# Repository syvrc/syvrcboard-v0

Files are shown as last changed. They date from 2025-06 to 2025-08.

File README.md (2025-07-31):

## syvrcboard v0
> `syvrcboard v0` was and is my very first attempt on making a custom mechanical keyboard from scratch although before making this i had made a [macropad](https://github.com/syvrc/syvrcpad) before  

| light bg                               |
| -------------------------------------- |
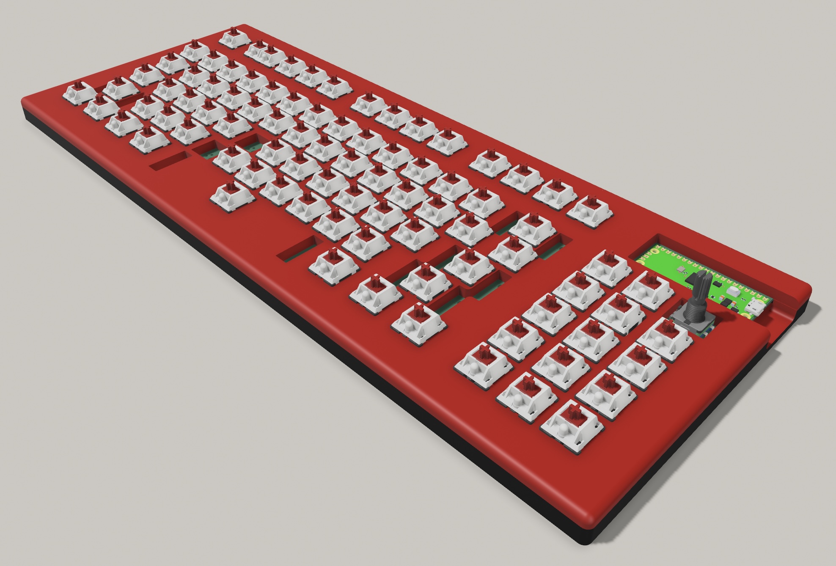
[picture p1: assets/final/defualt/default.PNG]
|  |

| dark bg                                                |
| ------------------------------------------------------ |
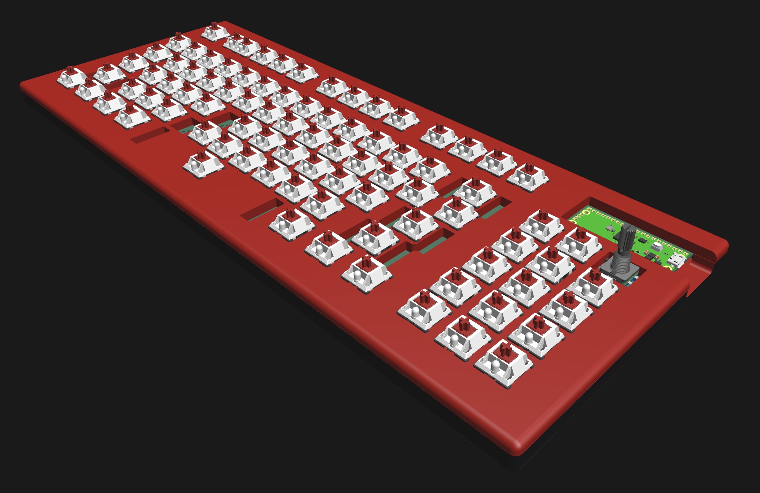
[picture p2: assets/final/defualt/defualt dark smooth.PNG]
|  |

> `syvrcboard v0` is a custom TKL Mechanical Keyboard with `10 Macro Keys`, a `Rotary Encoder Switch` and is powered by `Raspberry Pi Pico` board, the keyboard's silkscreen art is solely `demon slayer` based  

Features:
- 88x keys
- a rotary encoder switch for volume , brightness etc
- [custom TKL layout w/ 11 macrokeys](#layout)
- demon slayer themed pcb silkscreen art!!
- works with Raspberry Pi Pico
- KMK firmware (subject to change)
- sandwich mount

## schematic
| dev board (rpi pico)                | switch matrix
:------------------------------------:|:---------------------------------:
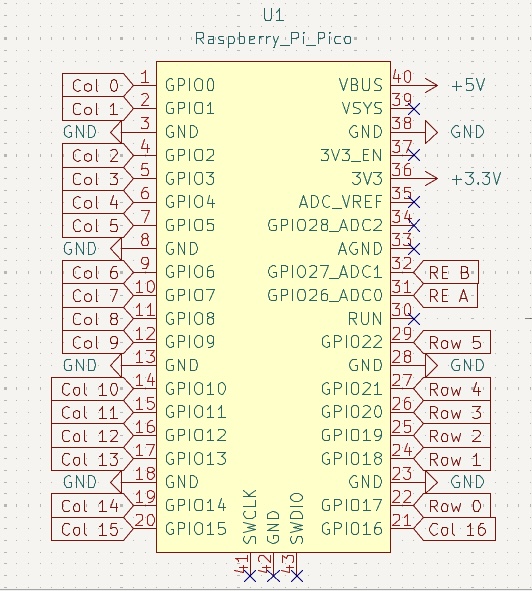
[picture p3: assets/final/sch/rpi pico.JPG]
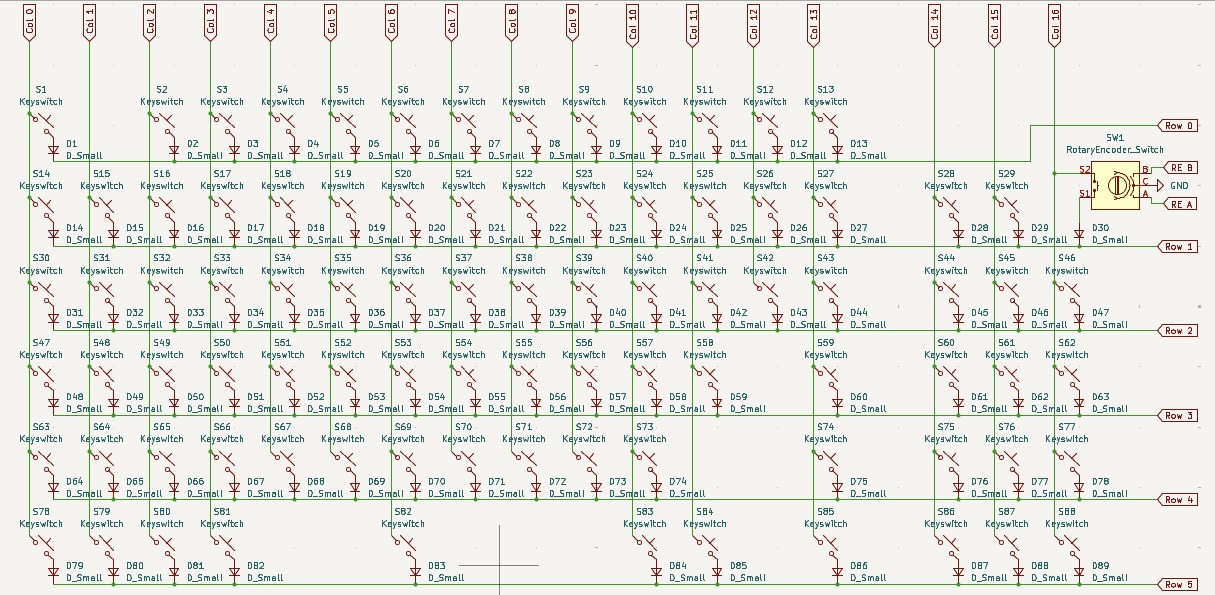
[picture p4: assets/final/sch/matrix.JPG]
 | 

## pcb
| front                            |
| -------------------------------- |
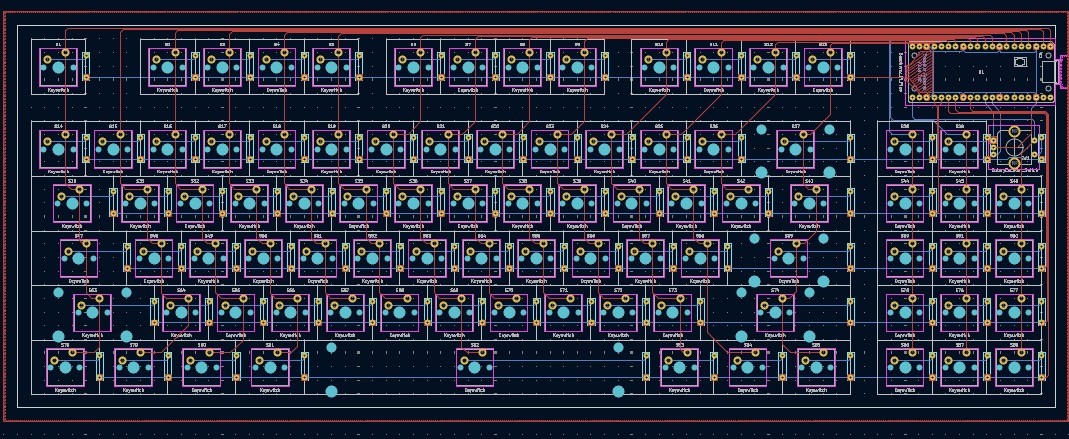
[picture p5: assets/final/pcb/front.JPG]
|  |

| back                            |
| ------------------------------- |
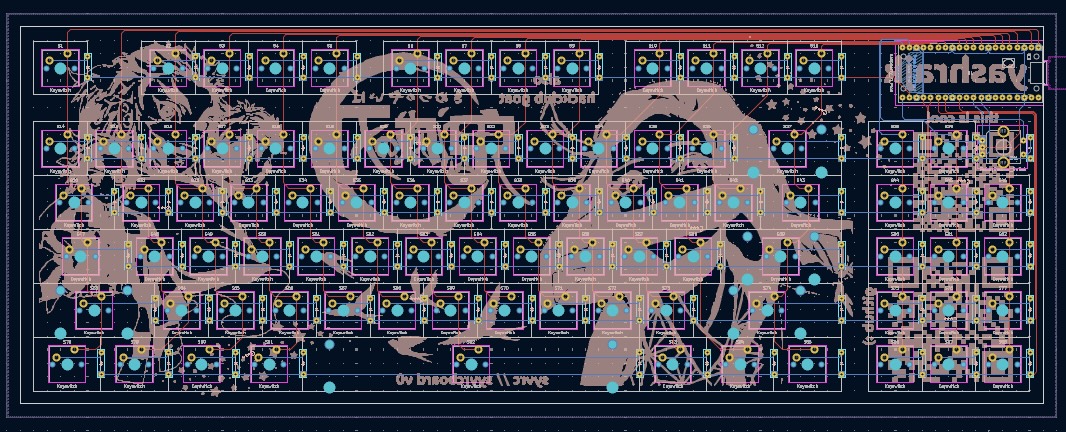
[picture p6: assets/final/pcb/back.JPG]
|  |

## case
| layers (diagonal view)                    | layers (right view)
:------------------------------------------:|:------------------------------------------:|
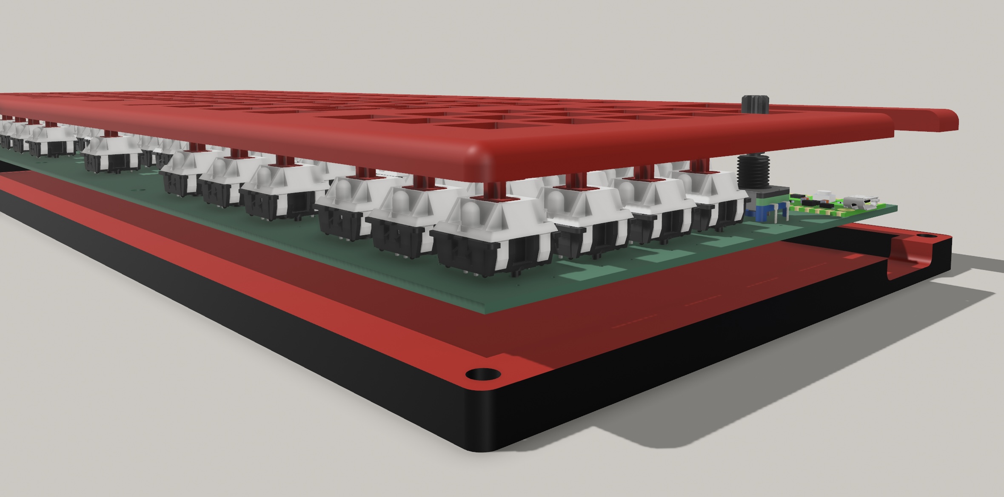
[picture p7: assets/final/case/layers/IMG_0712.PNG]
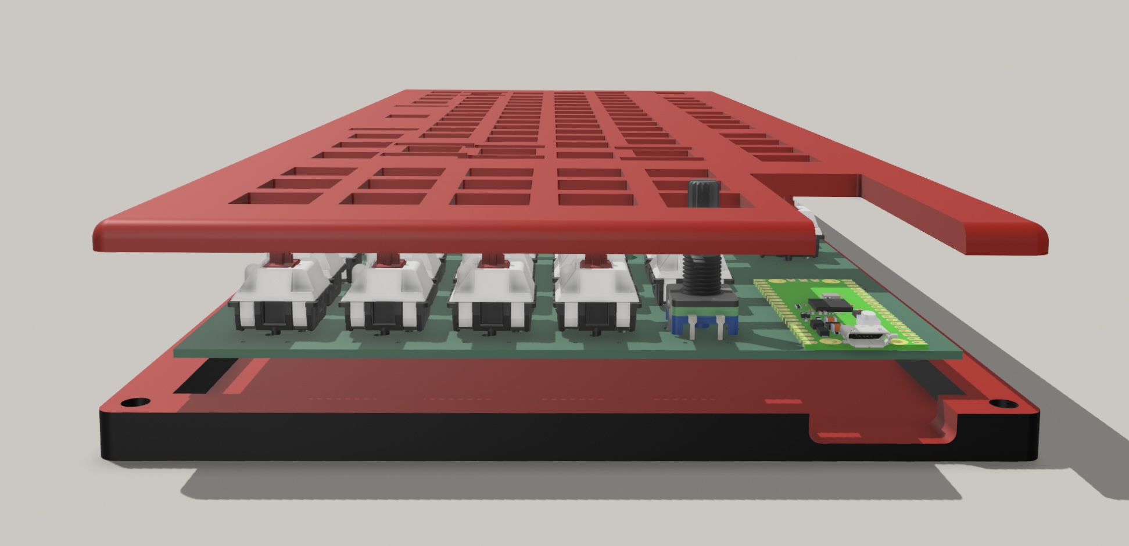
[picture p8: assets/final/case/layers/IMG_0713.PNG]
 | 

| plate                             |
| --------------------------------- |
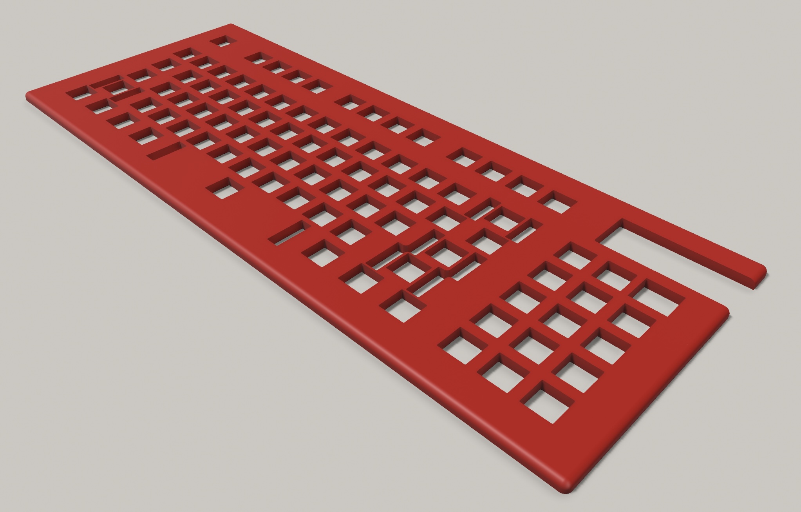
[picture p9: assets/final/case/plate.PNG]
|  |

| base                             |
| -------------------------------- |
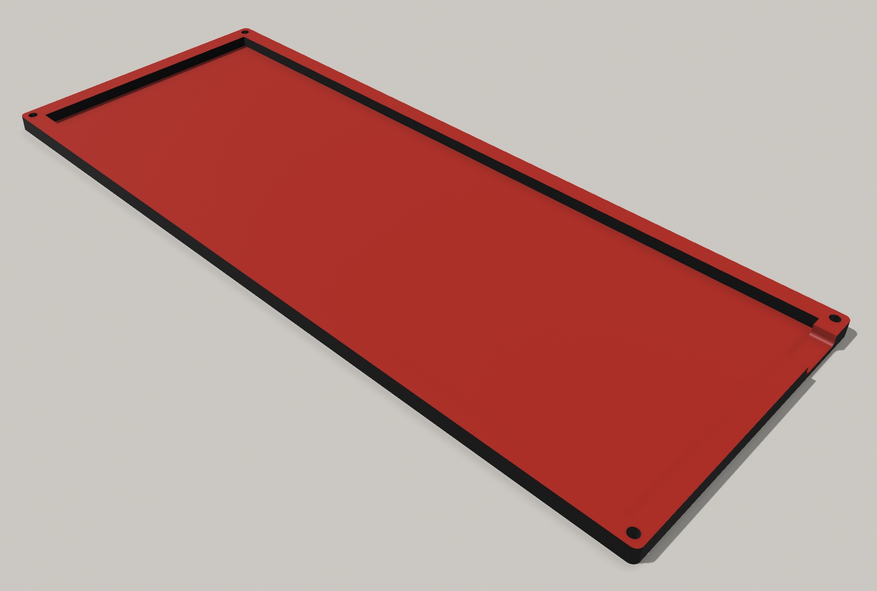
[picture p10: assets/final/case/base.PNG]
|  |

| assembled case                   |
| -------------------------------- |
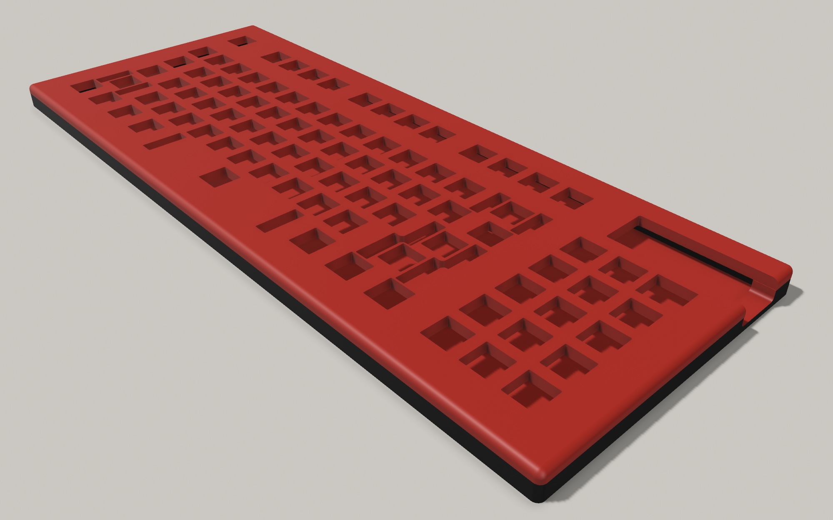
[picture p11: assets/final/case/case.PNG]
|  |

| component | thickness |
| --- | --- |
| plate | 5mm |
| base | 12mm |

## renders
| 3d pcb                          |
| ------------------------------- |
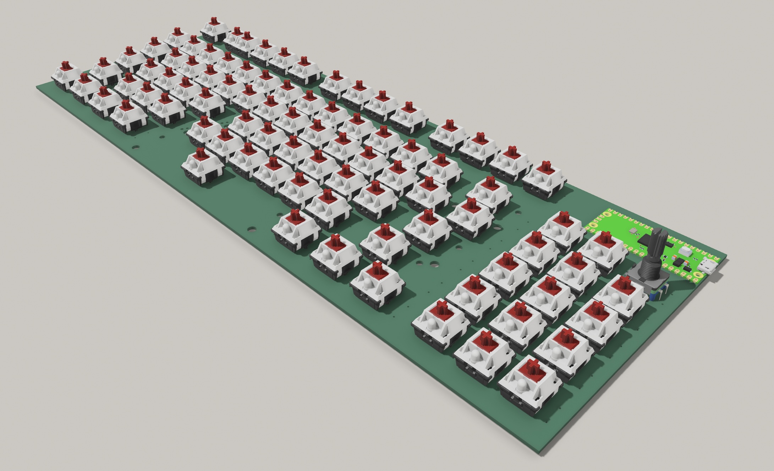
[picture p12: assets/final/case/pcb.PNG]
|  |

lined (light bg)                                             | lined (dark bg)
:-----------------------------------------------------------:|:-----------------------------------------------------------:
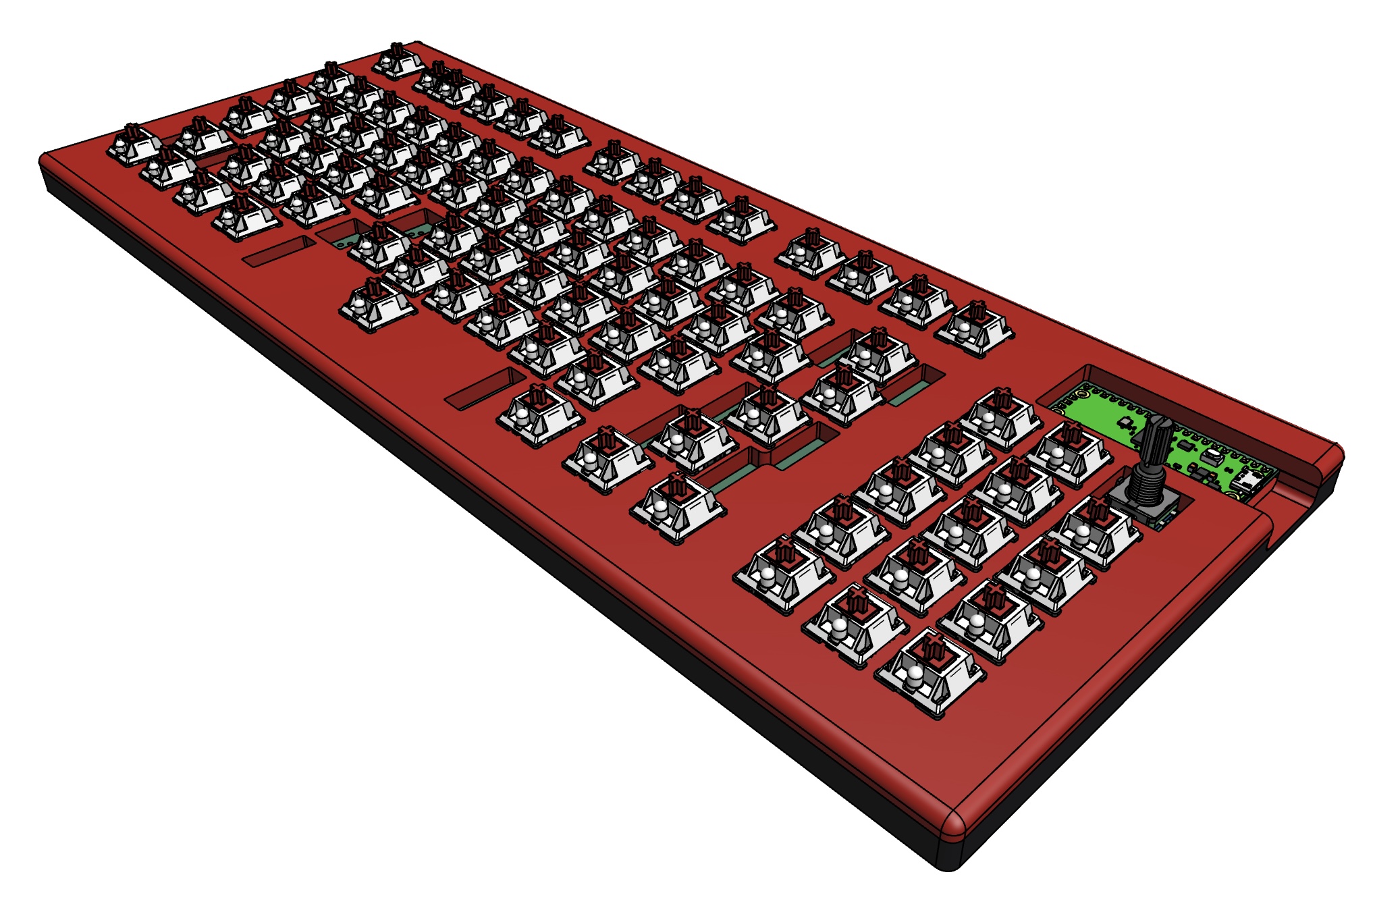
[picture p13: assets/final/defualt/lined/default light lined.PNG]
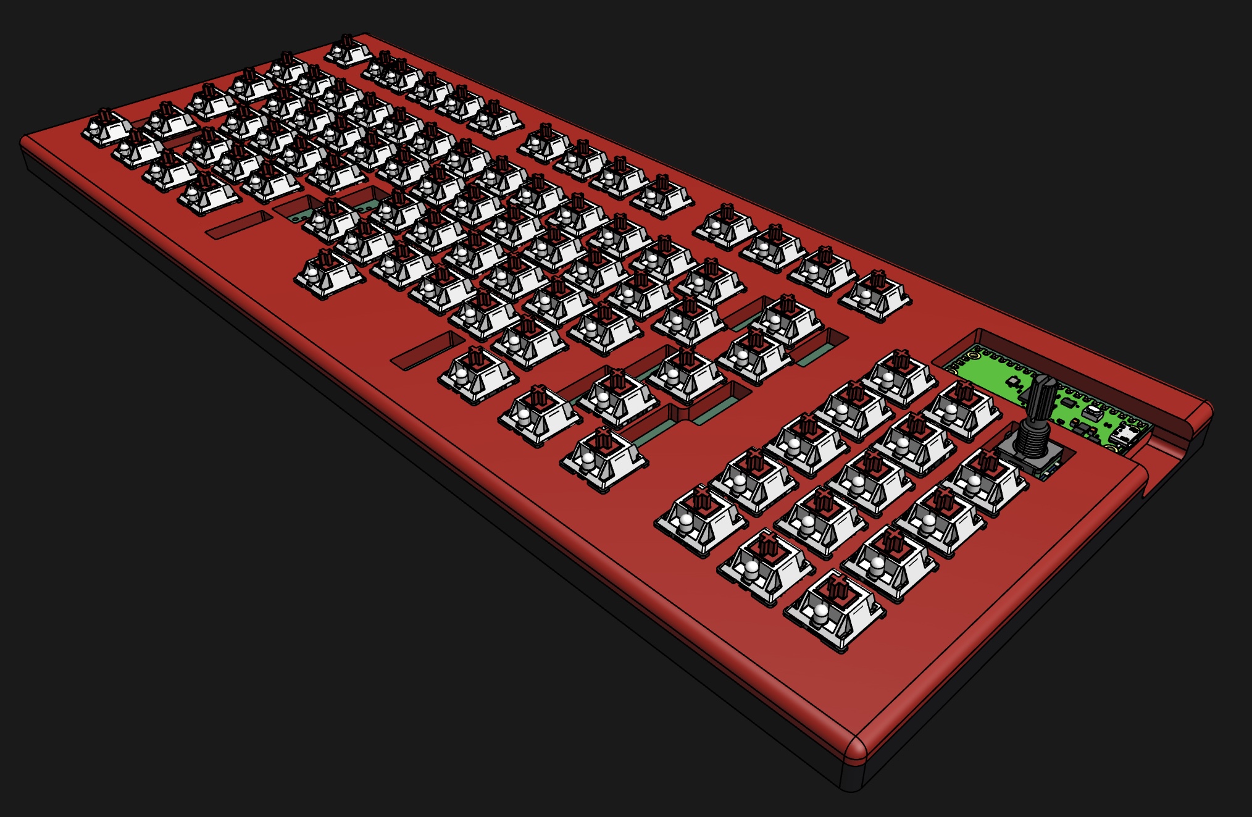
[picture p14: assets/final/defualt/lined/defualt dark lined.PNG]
 | 

| angle view                                        |
| ------------------------------------------------- |
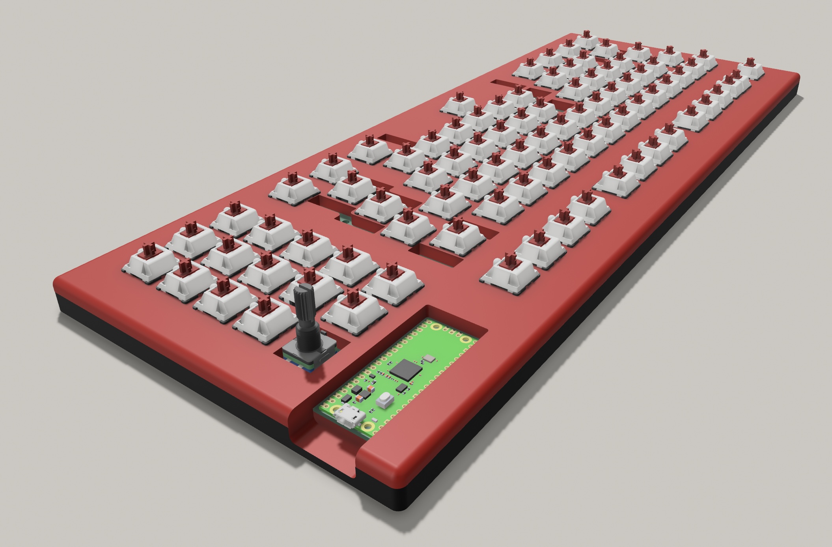
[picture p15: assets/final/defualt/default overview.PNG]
|  |

| side view                                  |
| ------------------------------------------ |
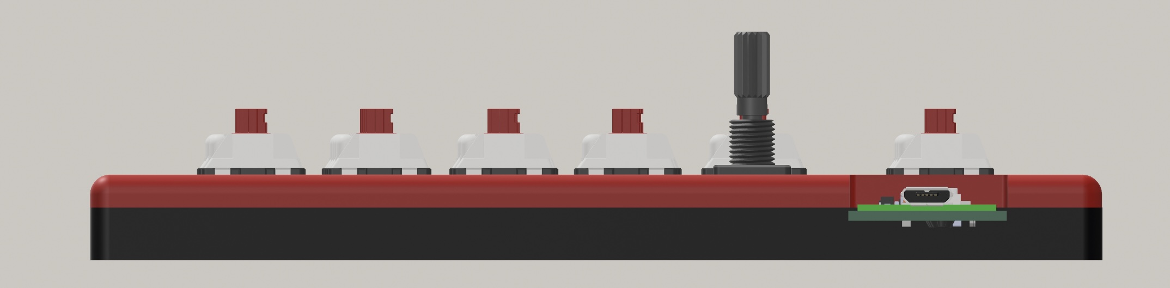
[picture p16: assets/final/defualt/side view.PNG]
|  |

## mounting
| light bg                                                          |
| ----------------------------------------------------------------- |
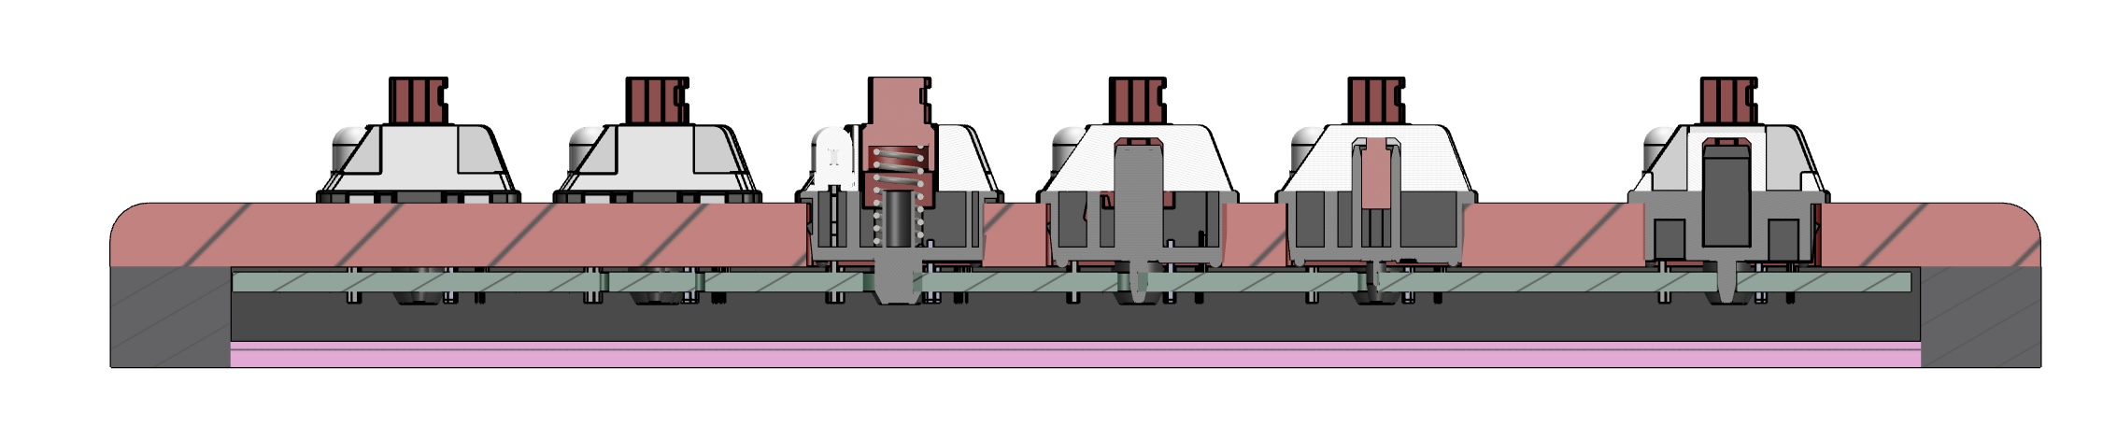
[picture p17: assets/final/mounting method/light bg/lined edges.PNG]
|  |

| dark bg                                                          |
| ---------------------------------------------------------------- |
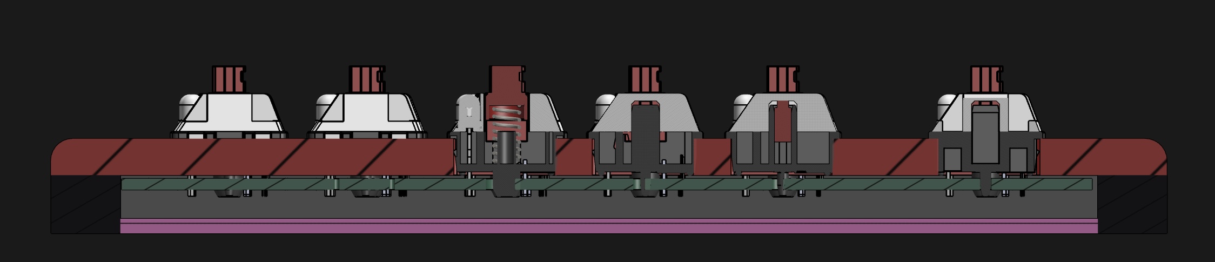
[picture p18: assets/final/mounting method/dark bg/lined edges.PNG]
|  |

> the mounting method used for this keyboard is generally called `sandiwich mount`, its the most beginner friendly mounting method if you are making the keyboard for the first time and dont have much experince wih 3d modelling, however, some people may find other mounting methods to be easier  

## layout
| unwired                              |
| ------------------------------------ |
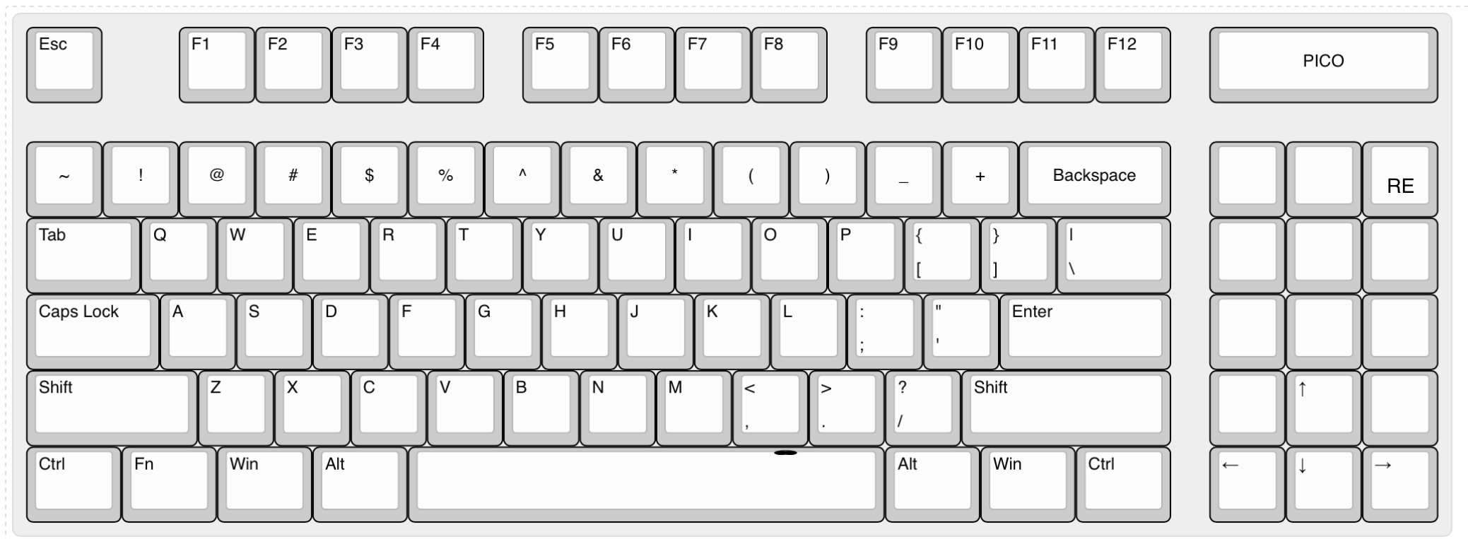
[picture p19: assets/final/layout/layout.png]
|  |

| wired                                        |
| -------------------------------------------- |
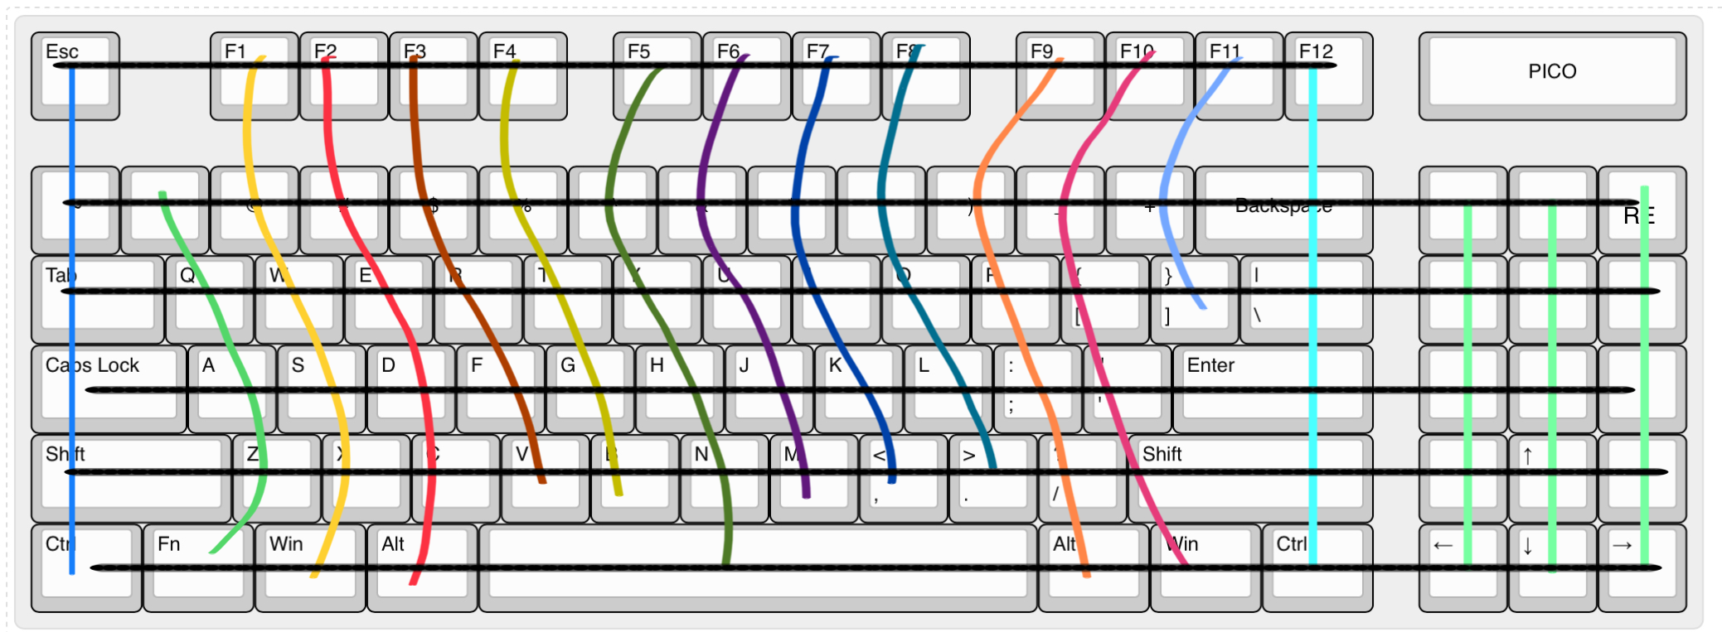
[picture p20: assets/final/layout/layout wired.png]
|  |

## BOM
| Name | Qty | Final Price - INR (USD) | Link |
| --- | --- | --- | ---|
| Cherry Profile PBT Keycaps | 1 | 1299 ($14.83) | [stackskb](https://stackskb.com/store/veekos-gradient-keycaps-cherry-profile-135-keys) |
| Gateron EF Curry Switches - pack of 10 | 9 | 1485 ($16.96) | [neomacro](https://neomacro.in/products/gateron-ef-curry?variant=48675835216150) |
| Durock Smokey Screw-In Stabilizers V2 (4+1 w/ 6.25u spacebar) | 1 | 1595 ($18.21) | [stackskb](https://stackskb.com/store/durock-smokey-screw-in-stabilizers-v2/) |
| Raspberry Pi Pico H (to match the footprint used) | 1 | 468 ($5.34) | [robocraze](https://robocraze.com/products/raspberry-pi-pico-h-pico-with-headers-soldered?variant=43243705467104) |
| Diode 1N4148 Through Hole – pack of 100 | 1 | 99 ($1.13) | [amazon](https://amzn.in/d/j3eLvoh) |
| M3 x 12mm Bolt – 15 Pieces | 1 | 149 ($1.70) | [amazon](https://amzn.in/d/7cpnJLY) |
| M3 Nuts – 12 Pieces | 1 | 99 ($1.13) | [amazon](https://amzn.in/d/7UQtsm8) |
| M3 x 5mm Heatset Insert – 25 Pieces | 1 | 170 ($1.94) | [amazon](https://amzn.in/d/ixybuAc) |
| PCB (Black Color) | NA  | NA | NA |
| Case (plate and base) | 1 | Printing Legion | - |
| EC11 Rotary Encoder Knob | 1 | Printing Legion | - |
| EC11 Rotary Encoder | 1 | NA | I have it |
| Surplex Sodering Iron Kit | 1 | 1449 ($16.53) | [amazon](https://amzn.in/d/b7gBDRM) |

Total cost of the build so far: 6813 INR | ($77.84)

## notes
the total amount is coming out to be `6813 ($77.84)` excluding the cost of `PCB` and `printing legion`

---
> ~~hit the like button~~ star the repo if you like my work!! 🚶‍♂️

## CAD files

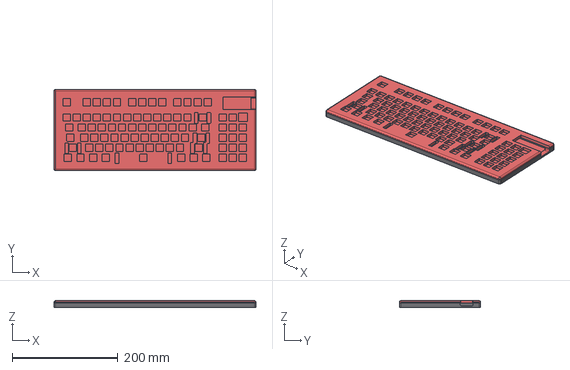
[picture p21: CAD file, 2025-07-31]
CAD/assembledcase.step
382.0 x 153.4 x 13.0 mm
plate gen
base

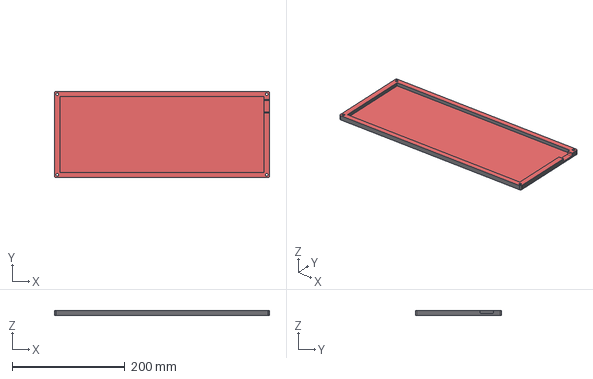
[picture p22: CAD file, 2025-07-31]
production/base.step
381.9 x 153.3 x 8.00 mm

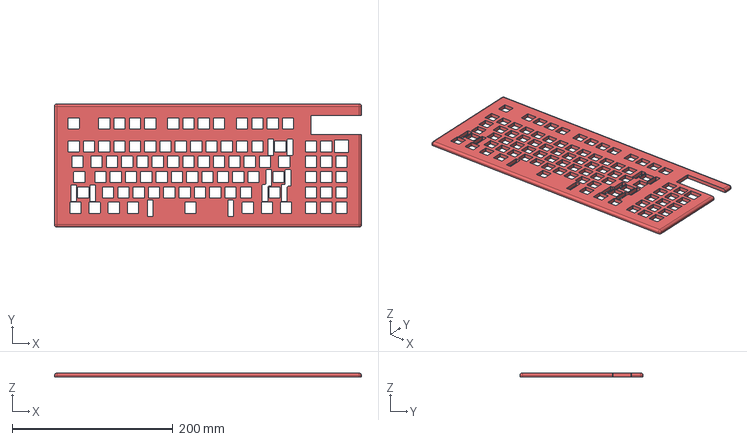
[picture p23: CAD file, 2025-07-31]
production/plate.step
381.9 x 153.4 x 5.00 mm

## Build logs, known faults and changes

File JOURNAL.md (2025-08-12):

---
title: "syvrcboard v0"
author: "@syvr"
description: "A Custom TKL Mechanical Keyboard"
created_at: "2025-06-02"
---

**Total time spent so far: 45hrs**
> note: the information in this file is not final and binding as this file is ment to be how I ended up with the final product, checkout [README.me](/README.md) to know the correct information.  

## First week of June: Research
> Watched hell lotta youtube videos to get a basic idea and all of what i wanted to make and how i wanted my keyboard to look like  
> I decided to go with a TKL Mechanical Keyboard layout with some customisations  

| Layout                            |
| --------------------------------- |
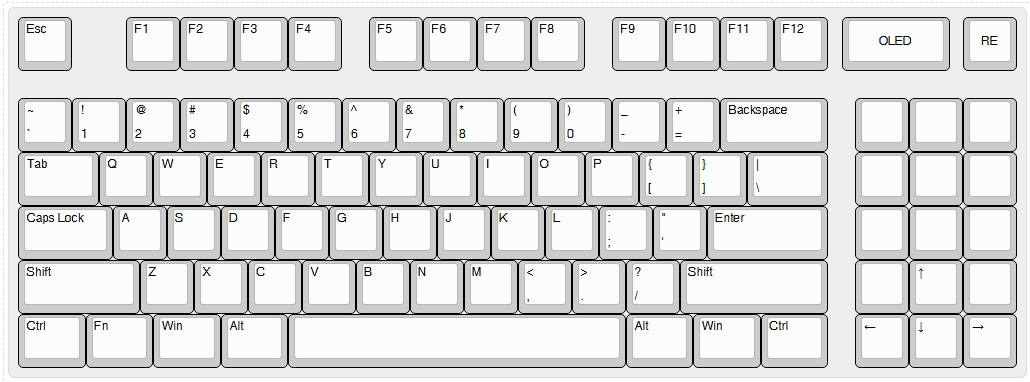
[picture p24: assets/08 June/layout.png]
|  |

> The keyboard is gonna have `11 macro keys (basically integrated macropad)`, a `Rotary Encoder Switch E11`, and a `0.91inch OLED Display 128x32` and is gonna use `STM32F411CEU6 Black Pill Board` as its mcu.  

> it was REALLY painful to find out symbol and footprint of `STM32F411CEU6 Black Pill Board`  

**Time spent: 6hrs**

## 08th June: Got started
| Basic Schematic                      |
| ------------------------------------ |
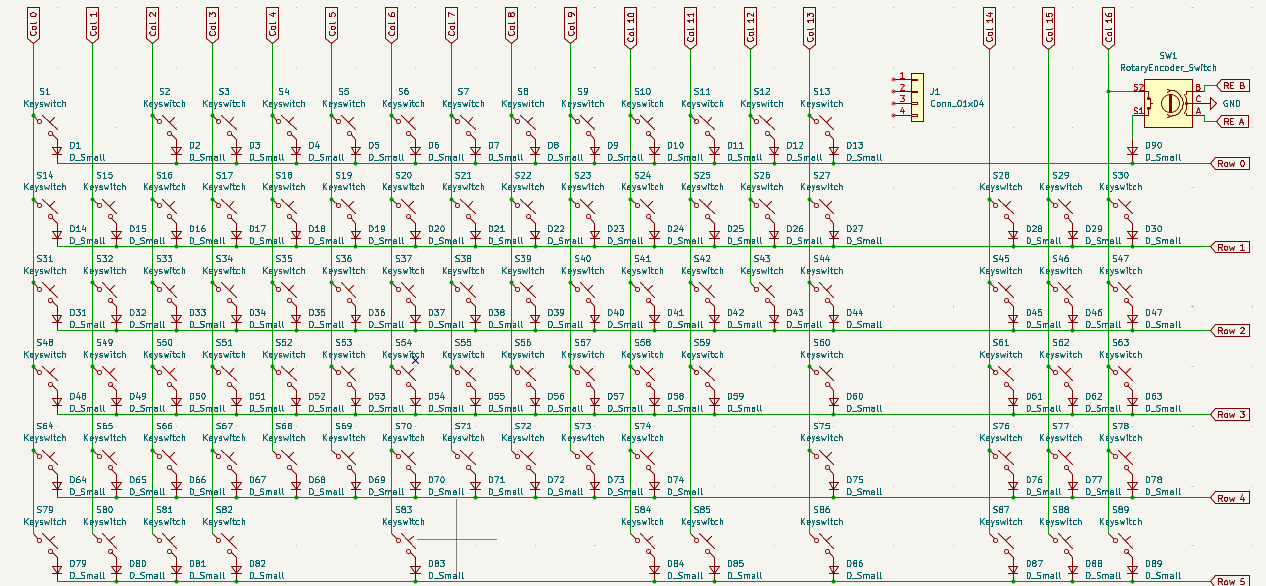
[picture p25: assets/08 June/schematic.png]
|  |
> Got done with keyboard matrix and wiring   

> Found out `STM32F411CEU6 Black Pill Board` on `EasyEDA`, converted `.json` files into symbol and footprint of it  
> Decided to make the keyboard Low profile since i dont really like the chunky ones(yet to finalise the switches and keycaps)  

**Time Spent: 5hrs**

## 9th June: Made the BOM
> I was tryna finalise the components and things which i was gonna work with but then found it difficult to keep a track of the money that was going into every component, so i made a BOM in `README.md` file, its currently at its second draft and is going to be updated throughout the project  

> I couldnt find a low profile keyswitch which was available in my area and was in budget, spent like 2hrs on it, then researched a bit about `cherry mx switches`, decided to go with `Cherry MX Silent Red` but it wasnt available in my area so then i asked for help in `#highway` and ended up with `Gateron EF Curry` switches since they are linear and LED compatible (im planning on adding LEDs to my keeb too)  

> The symbol of `STM32F411CEU6 Black Pill Board` wasnt symboling (basically it was very buggy, like smth was wrong with it ion know what) so i chose to go with `RPI Pico` (the reason why i wasnt using it before is cuz its has `micro USB interface` which i didnt want to use in my keyboard but however had to cuz I ran out of options)  

> i was indecisive if i was gonna handwire my keeb or make a pcb, so i ended up watching 3 to 4 videos about handwiring but then decided to go with the pcb  

> Spent hell lotta time making the BOM and finalizing the MCU

> to do list for tomorrow
> - [ ] complete the schematic  
>   - [ ] add a GPIO expander to the rpi pico  
>   - [ ] wire it all  
>   - [ ] add and setup leds  
> - [ ] complete the pcb  
>   - [ ] layout it  
>   - [ ] add some cool custom silkscreen art  
> - [ ] add the gpio expander used in the BOM  

**Time Spent: 7hrs**

## 06th and 07th July: major updates
> oh boy oh boy oh boy finally after like a month or sum of break im back!!!!!!!!!! i had my exams going and i got distracted by some other things, anw but when my pcb for `#hackpad` arrived it looked so cool that i got the feeling to continue the keeb again!!  
> we are back off VERY strong!! changes like: a whole layout change, sch done, pcb done and much more and feature changes has been made

| Final Layout                      |
| --------------------------------- |
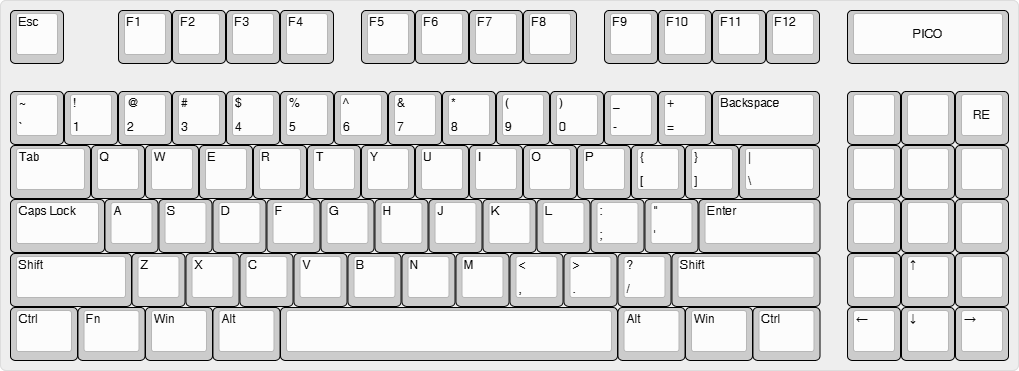
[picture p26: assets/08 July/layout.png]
|  |

> i originally thought of trying the double row method mentioned in the guide but it didnt seemed right for just one being short on one gpio pin and so i came up with this after like 2 or 3 layout variations  
> after brainstorming a bit in the slack with other ppl, i came up with this layout because i didnt wanted to use the gpio pins expanders as its too complex for me to understand  
> the thing(s) left now is the silk screen art and designing a case which should be done in a day or two (well hopefully)  

**Time Spent: 11hrs**

## 30th and 30st July: last part
> after procrastinating for a whole month i finally decided to get started and done with the 3d design of the case, designing took around like 10 to 12hrs and it was really hectic as i dont have much exp with 3d designing but still i was able to make a good case for my keeb also the rendering to take photos was so damn time consuimg cuz of like models of 80 keys in the file along with other things like the pcb model, rpi model the app kept on crashing and the rage bait was like 100000/10 fs. stil managed to get good render photos for the readme.md after a very long work to get the app working

| case                             |
| -------------------------------- |
|  |
> *there are more renders of the case in the [README.md](/README.md)

> i also updated the whole bom with the revsions and made the README.md file

**Time Spent: 16hrs**

### heres the layout used
["Esc",{x:1},"F1","F2","F3","F4",{x:0.5},"F5","F6","F7","F8",{x:0.5},"F9","F10","F11","F12"],
[{y:0.5},"~\n`","!\n1","@\n2","#\n3","$\n4","%\n5","^\n6","&\n7","*\n8","(\n9",")\n0","_\n-","+\n=",{w:2},"Backspace",{x:0.5,a:7},"","",""],
[{a:4,w:1.5},"Tab","Q","W","E","R","T","Y","U","I","O","P","{\n[","}\n]",{w:1.5},"|\n\\",{x:0.5,a:7},"","",""],
[{a:4,w:1.75},"Caps Lock","A","S","D","F","G","H","J","K","L",":\n;","\"\n'",{w:2.25},"Enter",{x:0.5,a:7},"","",""],
[{a:4,w:2.25},"Shift","Z","X","C","V","B","N","M","<\n,",">\n.","?\n/",{w:2.75},"Shift",{x:0.5,a:7},"",{a:4},"↑",{a:7},""],
[{a:4,w:1.25},"Ctrl",{w:1.25},"Fn",{w:1.25},"Win",{w:1.25},"Alt",{a:7,w:6.25},"",{a:4,w:1.25},"Alt",{w:1.25},"Win",{w:1.25},"Ctrl",{x:0.5},"←","↓","→"]

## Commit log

2025-06-09 bom: first draft
2025-06-09 bom: second draft
2025-06-09 bom: second draft fix
